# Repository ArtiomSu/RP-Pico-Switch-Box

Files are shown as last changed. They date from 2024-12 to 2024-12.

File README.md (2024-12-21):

# Pico Switch Box

A fun little box for playing around with switches and leds.

Features a Game where you need to match the leds. You will be timed on how long it takes you to complete the game. By default there is only 5 levels but you can increase it to however many you want by changing `self.level_max = 5` inside `game.py`

Control pc power button using a sequence.

The files I created for 3d printing are available inside the stl folder in this repo.

I was going to power it via a powerbank but since the pico draws barely any power the powerbank I have shuts off after 30 seconds. So I'm just going to power it via a usb port. Thats why you will see some extrusions in the 3d model for the power bank, you can remove those in blender to save some materials.

Top | Side | Bottom
:---:|:---:|:---:
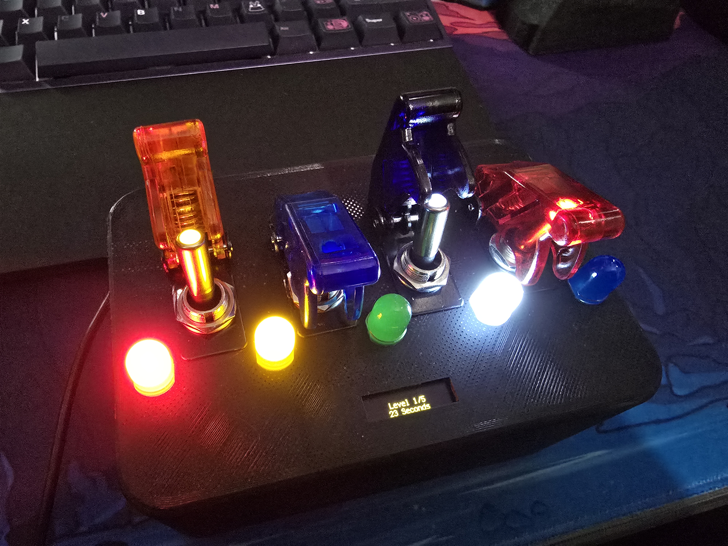
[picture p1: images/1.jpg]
running_game
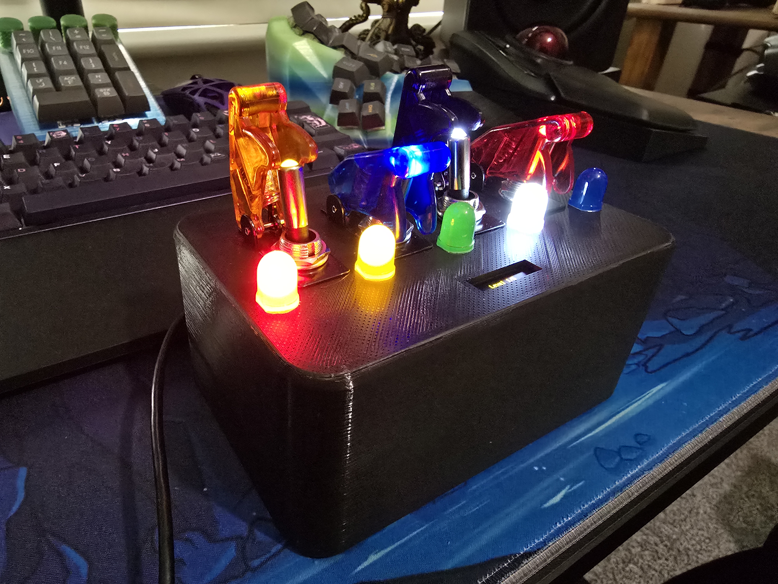
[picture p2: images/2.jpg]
running_game_side
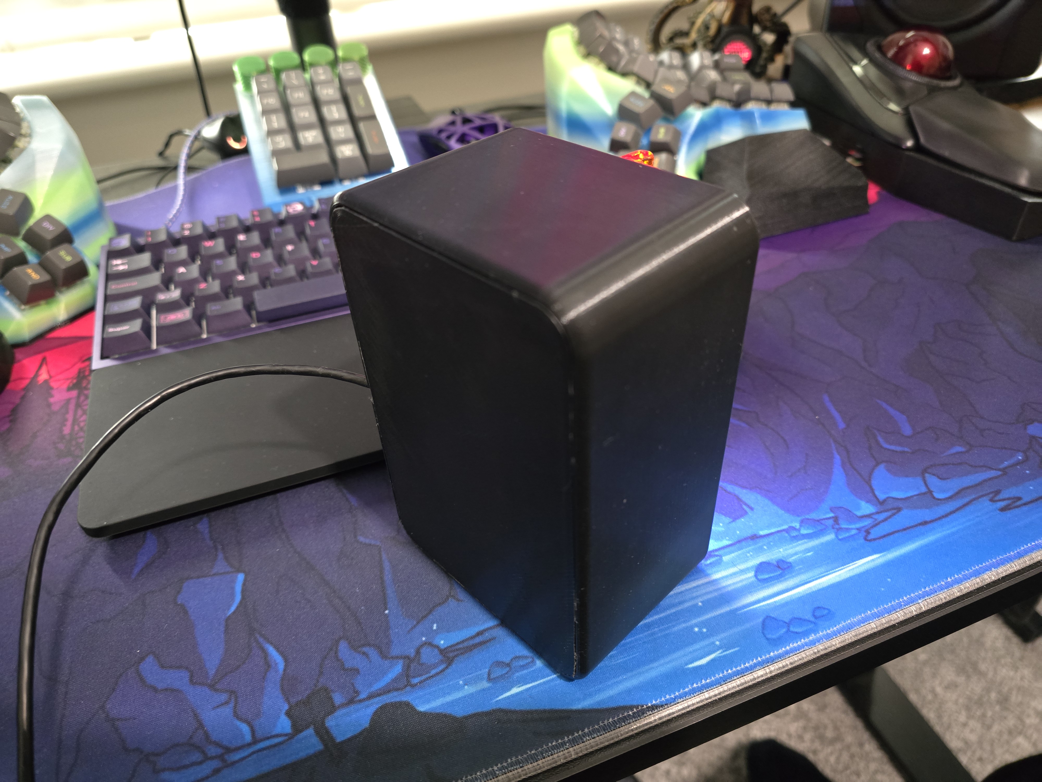
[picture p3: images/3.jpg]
running_game_bottom
 |  | 

# Hardware

All hardware is purchased from Aliexpress as its cheaper

1. Raspberry pi pico
2. 5 Big LEDs
3. 128x32 oled screen
4. 4 switch led combos
5. 9 325 ohm resistors
6. 4 10k ohm resistors
7. 8 small magnets

# Setup Software

Download and install Circuit python to the pico.

You will also need to download and copy some circtuit python libraries to the pico. Download the whole collection and then copy the following to the pico.

Also copy over the python files from this repo.
(can run copyToPico.sh/bat)

Your pico should look like this.

```
PICO
 | lib
    | adafruit_display_text
    | adafruit_hid
    | adafruit_displayio_ssd1306.mpy
    | adafruit_pixelbuf.mpy
    | neopixel.mpy
 | main.py
 | display.py
 | hardware.py
 | ledNormal.py
 | switchAndLed.py
 | hardware.py
 | tools.py
```

# Setup Hardware

For the display I use `i2c = busio.I2C(board.GP5, board.GP4)  # GP5 for SCL and GP4 for SDA` (see `display.py`). and the usual ground and power pins.

For the switches and leds see `hardware.py`.

The big normal leds are defined in `normalLedsPins = [board.GP16, board.GP17, board.GP18, board.GP19 ,board.GP20]`

The leds that are on the switches are defined in `switchLedPins = [board.GP15, board.GP14, board.GP13, board.GP12]`

The switch pins themselves for checking if the switch is closed or open are defined in `switchPins = [board.GP11, board.GP10, board.GP9, board.GP8]`

For led resistors I will use 325 ohm, for switch pulldown resistors I will use a 10k ohm.

### Notes on the switch and led combo component from aliexpress
```txt
[ground] [led] []
led is only on when switch is on..

[ground] [] [led]
led is always on...

ground seems to be only for the led. doesnt have any effect on the switch itself

switch only worksw with these two pins connected
[] [wire 1] [wire 2]

so to make both of them work switch will only be able to activate if the led is on.
So for led I will use this
[ground] [] [led]

then the pico can just listen on the middle pin

Wiring the switch will be as follows

[] [switch input] [led output]
       ^
       |
       10k ohm resistor
       |
       Ground

Wiring the switch leds will be as follows
[325 ohm resistor] [] [led output]
    ^
    |
    Ground
```

#### The wiring looks like this then

_ | _ | _
:---:|:---:|:---:
wiring_1 | wiring_2 | wiring_3

# Turning off pc addition

For this I used a 2N2222 NPN transistor. Get it from aliexpress.

The wiring for the transistor looks like this when the flat edge is facing you

```txt
         +---+
         |   |
         +---+
         | | |
         | | |
       pc+ |
       1k resistor
           |
         GPIO1
             pc-  
```

so the middle pin goes to a 1k resistor then to GPIO 1 on the pico. The other two pins just connect directly to the pc power pins.

Also to enable switching between game mode and power mode, I added a wire/switch across GPIO 6 and ground. when a connection is made, it will go into power mode and when there is no power flowing through, it will go into game mode.

_ | 
:---:|
wiring_pc_power

# Videos
Part 1 | Part 2
:---:|:---:
part1 (https://www.youtube.com/watch?v=SvOWJSmI67I) | part2 (https://www.youtube.com/watch?v=67JiJsYJK44)

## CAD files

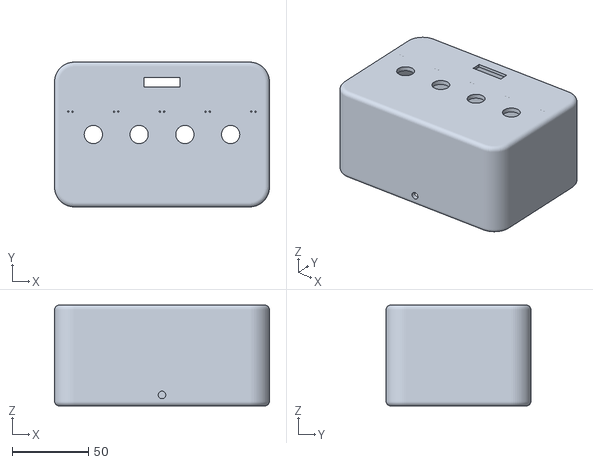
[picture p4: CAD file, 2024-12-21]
stl/picoBoxGame-magnet_holder.stl
140.9 x 94.9 x 66.0

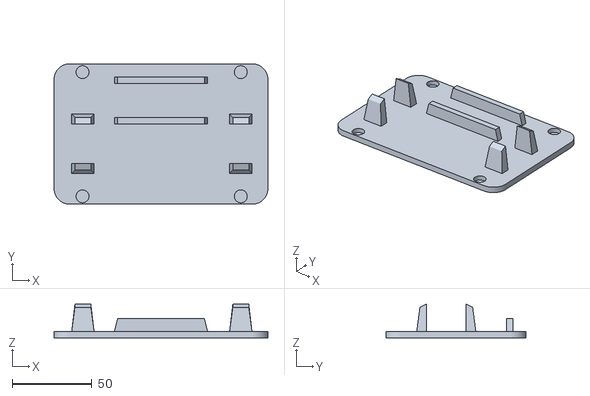
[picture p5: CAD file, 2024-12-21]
stl/picoBoxGameBase.stl
133.9 x 87.9 x 21.0

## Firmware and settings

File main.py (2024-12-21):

from game import Game
from power import Power
from hardware import Hardware

hardware = Hardware()

# 0 is running game
# 1 is running pc power.
run_mode = 1

def checkRunMode():
    global run_mode
    last_run_mode = run_mode
    current = hardware.get_setting()
    if current:
        run_mode = 1
    else:
        run_mode = 0

    if last_run_mode != run_mode:
        return True
    
    return False

if __name__ == "__main__":
    game = Game(hardware)
    power = Power(hardware)
    checkRunMode()
    while True:
        if checkRunMode():
            game.reset()
            power.reset()
        if run_mode == 0:
            game.run_game_next_state()
        else:
            power.run_next_check()

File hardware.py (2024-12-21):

import board
from display import Display
from ledNormal import LedNormal
from switchAndLed import SwitchAndLed
import digitalio
import time

class Hardware:
    display = None
    normalLedsPins = [board.GP16, board.GP17, board.GP18, board.GP19 ,board.GP20]
    normalLedColours = ["red", "yellow", "green", "white", "blue"]
    switchLedPins = [board.GP15, board.GP14, board.GP13, board.GP12]
    switchPins = [board.GP11, board.GP10, board.GP9, board.GP8]
    switchColours = ["orange", "blue", "purple", "red"]
    powerPin = board.GP1
    settingPin = board.GP6

    normalLeds = []
    switchAndLeds = []
    powerSwitch = None
    settingSwitch = None

    def __init__(self):
        self.display = Display()

        normalLedCounter = 0
        for normalLedPin in self.normalLedsPins:
            self.normalLeds.append(LedNormal(normalLedPin, self.normalLedColours[normalLedCounter], normalLedCounter))
            normalLedCounter = normalLedCounter + 1
        
        for i in range(len(self.switchLedPins)):
            self.switchAndLeds.append(SwitchAndLed(self.switchLedPins[i], self.switchColours[i], i, self.switchPins[i], i))

        self.powerSwitch = digitalio.DigitalInOut(self.powerPin)
        self.powerSwitch.direction = digitalio.Direction.OUTPUT
        self.powerSwitch.value = False

        self.settingSwitch = digitalio.DigitalInOut(self.settingPin)
        self.settingSwitch.direction = digitalio.Direction.INPUT
        self.settingSwitch.pull = digitalio.Pull.UP
    
    def turnOffAllLeds(self):
        for led in self.normalLeds:
            led.setLed(False)
        
        for led in self.switchAndLeds:
            led.setLed(False)

    def startupAnimationOled(self, frame, frameCount):
        self.display.animateText("+-------------+", frame, frameCount, "top", 0)
        self.display.animateText("| Switch  Box |", frame, frameCount, "centre", 1)
        self.display.animateText("| By ArtiomSu |", frame, frameCount, "bottom", 2)
        self.display.display.refresh()

    def printLogo(self):
        self.display.printText("+-------------+", "top", 0, "centre")
        self.display.printText("| Switch  Box |", "centre", 1, "centre")
        self.display.printText("| By ArtiomSu |", "bottom", 2, "centre")

    def powerOnAnimation(self):
        for l in self.normalLeds:
            l.setLed(True)
            time.sleep(0.25)

    def startupAnimationLeds(self, frame):
        if frame < len(self.normalLeds):
            self.normalLeds[frame].setLed(True)
            if(frame > 0):
                self.normalLeds[frame - 1].setLed(False)
            return False

        self.normalLeds[len(self.normalLeds) -1].setLed(False)
        frame = frame - len(self.normalLeds)

        if frame < len(self.switchAndLeds):
            self.switchAndLeds[frame].setLed(True)
            if(frame > 0):
                self.switchAndLeds[frame - 1].setLed(False)
            return False

        self.switchAndLeds[len(self.switchAndLeds) -1].setLed(False)
        frame = frame - len(self.switchAndLeds)

        if frame < len(self.switchAndLeds):
            self.switchAndLeds[(len(self.switchAndLeds) - 1) - frame].setLed(True)
            if(frame > 0):
                self.switchAndLeds[len(self.switchAndLeds) - frame].setLed(False)
            return False
        
        self.switchAndLeds[0].setLed(False)
        frame = frame - len(self.switchAndLeds)

        if frame < len(self.normalLeds):
            self.normalLeds[(len(self.normalLeds) - 1) - frame].setLed(True)
            if(frame > 0):
                self.normalLeds[len(self.normalLeds) - frame].setLed(False)
            return False

        self.normalLeds[0].setLed(False)
        #self.turnOffAllLeds()
        return True

    def startupAnimation(self, frame):
        if frame == 0:
            self.display.clear()
        totalFrames = (len(self.normalLeds) * 2) + (len(self.switchAndLeds) * 2)
        self.startupAnimationOled(frame, totalFrames)
        if self.startupAnimationLeds(frame):
            self.display.clear()
            return True
        return False
    
    def enableSwitchInput(self):
        for led in self.switchAndLeds:
            led.setLed(True)

    def getSwitchesOutput(self):
        output = []
        for switch in self.switchAndLeds:
            output.append(switch.isSwitchOn())
        return output
    
    def turnOff(self):
        self.turnOffAllLeds()
        self.display.clear()
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

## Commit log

2024-12-21 game fully working
    [picoBoxGame-magnet_holder.stl, picoBoxGameBase.stl]
2024-12-21 add support for power mode and support for switching between modes
